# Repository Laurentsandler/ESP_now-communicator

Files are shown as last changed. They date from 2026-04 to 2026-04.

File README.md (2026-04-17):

# ESP-Now long range communicator

## Description

A long range text based communicator based on esp-now

## Motivation

My school banned phones, so I wanted to build a small communicator that me and my friend can use.

## Hardware Design

The custom PCB was designed using EasyEDA, and is 2 layers. The battery fits behind it, the case has locked in buttons.

EasyEDA Project Link:  https://oshwlab.com/capyvara0/esp_now-communicator

### PCB Layout & 3D Renders





### Case





Onshape Project Link: [<ONSHAPE_PROJECT>](https://cad.onshape.com/documents/b60efe79f3e39b50ec4340e8/w/98b2614707c57877de69ff90/e/7286b2544836b97ccc1a2148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)

## Features

- Sending text based data between devices
- Offline detection
- Secure transmition

## System Architecture

```text
Device 1 <----> Device 2
```

## Software Dependencies

Install these libraries:
- #include <Arduino.h>
- #include <WiFi.h>
- #include <esp_now.h>
- #include <Wire.h>
- #include <Adafruit_GFX.h>
- #include <Adafruit_SH110X.h>
  
## Configuration

### Module Setup
1. Connect battery to JST connector
3. Connect the antenna to the esp32 module, and mount it through the hole in the case.
4. Wire the Display: Connect the 1.3" OLED display using I2C (SDA to pin `8`, SCL to pin `9`, VCC to 3.3V, and GND to Ground).
5. Upload Firmware: Open the project in PlatformIO and flash the exact same codebase (`src/main.cpp`) to both ESP32-S3 boards.

## Usage

- Auto-Discovery: Wait up to 3 seconds. The devices will broadcast heartbeat PINGs and automatically lock onto each other's MAC addresses using the PAIRING_SECRET.
- Verify Status: Check the OLED screen; the top status indicator should automatically update from Status: OFFLINE to Status: ONLINE.
- Communicate: Use the 0-9 buttons to type messages (T9 multi-tap style), the bottom-left button (M) to backspace, and the bottom-right button (S) to send the message privately to the paired device

## Bill of Materials (BOM)

| Item | Description | Purpose | Qty | Unit Price | Link | Supplier |
|---|---|---|-----|---|---|---|
| JLCPCB PCB | Custom PCB | Main computer that interfaces with components | 1 | $64.43 | N/A | JLCPCB |
| 1.3" OLED I2C Display (128x64, White) | OLED Display Module | Display messages and content | 2 | $6.36 | [Link](https://fr.aliexpress.com/item/4000191763740.html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) | AliExpress |
| 8dBi WiFi Antenna (2.4GHz) | External WiFi Antenna | Supports long-distance communication | 1 | $5.66 | [Link](https://fr.aliexpress.com/item/1005007449002305.html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) | AliExpress |
| 103450 3.7V 2000mAh LiPo Battery | Lithium Polymer Battery | Main power source | 2 | $7.81 | [Link](https://fr.aliexpress.com/item/1005011659846396.html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) | AliExpress |

## Total Cost
**$84.26**

## License

MIT License

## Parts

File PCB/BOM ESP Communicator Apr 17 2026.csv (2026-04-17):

ID | Name | Designator | Footprint | Quantity | Manufacturer Part | Manufacturer | Supplier | Supplier Part | Price
1 | 10uF | C1,C9 | C0603 | 2 | CL10A106KP8NNNC | SAMSUNG(三星) | LCSC | C19702 | 0.008
2 | 22uF | C2 | C0603 | 1 | CL10A226MQ8NRNC | SAMSUNG(三星) | LCSC | C59461 | 0.009
3 | 100nF | C3 | C0603 | 1 | VJ0603Y104JXQCW1BC | VISHAY(威世) | LCSC | C3834925 | 0.081
4 | 10uF | C4 | C0805 | 1 | CL21A106KAYNNNE | SAMSUNG(三星) | LCSC | C15850 | 0.022
5 | 100nF | C5 | C0805 | 1 | CC0805KRX7R9BB104 | YAGEO(国巨) | LCSC | C49678 | 0.005
6 | 47uF | C6 | C0805 | 1 | C0805X5R476M100NT | SANYEAR(叁叶源) | LCSC | C466799
7 | B5819W_C8598 | D1 | SOD-123_L2.7-W1.6-LS3.7-RD-1 | 1 | B5819W SL | CJ(江苏长电/长晶) | LCSC | C8598 | 0.024
8 | FC-2012HRK-620D | LED1 | LED0805-RD | 1 | NCD0805R1 | 国星光电 | LCSC | C84256 | 0.013
9 | AO3401A | Q1 | SOT-23_L2.9-W1.3-P1.90-LS2.4-BR | 1 | AO3401A | AOS | LCSC | C15127 | 0.059
10 | 5.1kΩ | R1,R2 | R0603 | 2 | 0603WAF5101T5E | UNI-ROYAL(厚声) | LCSC | C23186 | 0.002
11 | 100kΩ | R3 | R0603 | 1 | 0603WAF1003T5E | UNI-ROYAL(厚声) | LCSC | C25803 | 0.002
12 | 2kΩ | R4 | R0603 | 1 | 0603WAF2001T5E | UNI-ROYAL(厚声) | LCSC | C22975 | 0.002
13 | 22Ω | R7,R8 | R0603 | 2 | FRC0603F22R0TS | FOJAN(富捷) | LCSC | C2930077 | 0.001
14 | 10kΩ | R9,R10 | R0603 | 2 | 0603WAF1002T5E | UNI-ROYAL(厚声) | LCSC | C25804 | 0.001
15 | 1kΩ | R5 | R0805 | 1 | FRR0805J102 TS | FOJAN(富捷) | LCSC | C49196827 | 0.002
16 | 100kΩ | R6 | R0805 | 1 | 0805W8F1003T5E | UNI-ROYAL(厚声) | LCSC | C149504 | 0.003
17 | MST-12D18G4 SPDT SLIDE SWITCH | SW1 | SW-SMD_MST-12D18G4-SPDT-SLIDE-SWITCH | 1 | MST-12D18G4 SPDT Slide Switch | SHOU HAN(首韩) | LCSC | C49023767 | 0.082
18 | TS-1088-AR02016 | SW3,SW4 | SW-SMD_L3.9-W3.0-P4.45 | 2 | TS-1088-AR02016 | XUNPU(讯普) | LCSC | C720477 | 0.056
19 | 4*4*1.7 | SW5,SW6,SW7,SW8,SW9,SW10,SW11,SW12,SW13,SW14,SW15,SW16 | SW-SMD_4P-L5.2-W5.2-P3.70-LS6.5 | 12 | 4*4*1.7 贴片 | BOOMELE(博穆精密) | LCSC | C10852 | 0.022
20 | TP4054A | U1 | SOT-23-5_L2.9-W1.6-P0.95-LS2.8-TL | 1 | TP4054A | YONGYUTAI(永裕泰) | LCSC | C33551022 | 0.029
21 | AP2112K-3.3TRG1 | U3 | SOT-25-5_L2.9-W1.6-P0.95-LS2.8-BL | 1 | AP2112K-3.3TRG1 | DIODES(美台) | LCSC | C51118 | 0.147
22 | 1.3Inch I2C OLED MODULE | U4 | OLED 1.3 INCH | 1
23 | ESP32-S3-WROOM-1U-N8 | U17 | WIRELM-SMD_ESP32-S3-WROOM-1U | 1 | ESP32-S3-WROOM-1U-N8 | ESPRESSIF(乐鑫) | LCSC | C2980297 | 4.942
24 | TYPE-C-31-M-12 | USBC1 | USB-C_SMD-TYPE-C-31-M-12_1 | 1 | TYPE-C-31-M-12 | 韩国韩荣 | LCSC | C165948 | 0.185

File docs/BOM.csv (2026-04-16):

Item | Description | Purpose | Qty | Unit Price | Link | Supplier
JLCPCB PCB | Custom PCB | Main computer that interfaces with components | 1 | 64.43 | N/A | JLCPCB
1.3" OLED I2C Display (128x64 White) | OLED Display Module | Display messages and content | 2 | 6.36 | https://fr.aliexpress.com/item/4000191763740.html | AliExpress
8dBi WiFi Antenna (2.4GHz) | External WiFi Antenna | Supports long-distance communication | 1 | 5.66 | https://fr.aliexpress.com/item/1005007449002305.html | AliExpress
103450 3.7V 2000mAh LiPo Battery | Lithium Polymer Battery | Main power source | 2 | 7.81 | https://fr.aliexpress.com/item/1005011659846396.html | AliExpress

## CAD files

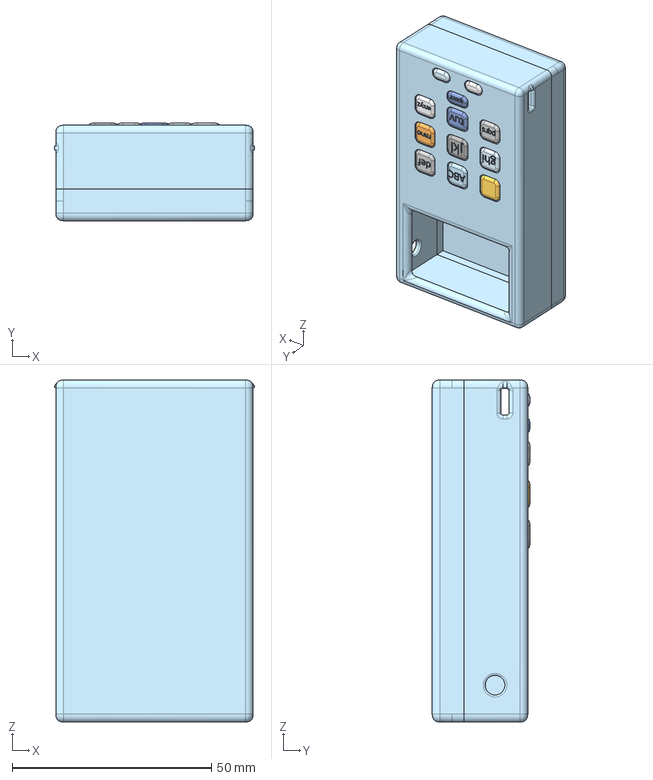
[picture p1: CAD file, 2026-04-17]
CAD/Full Assembly.step
50.3 x 24.5 x 85.9 mm

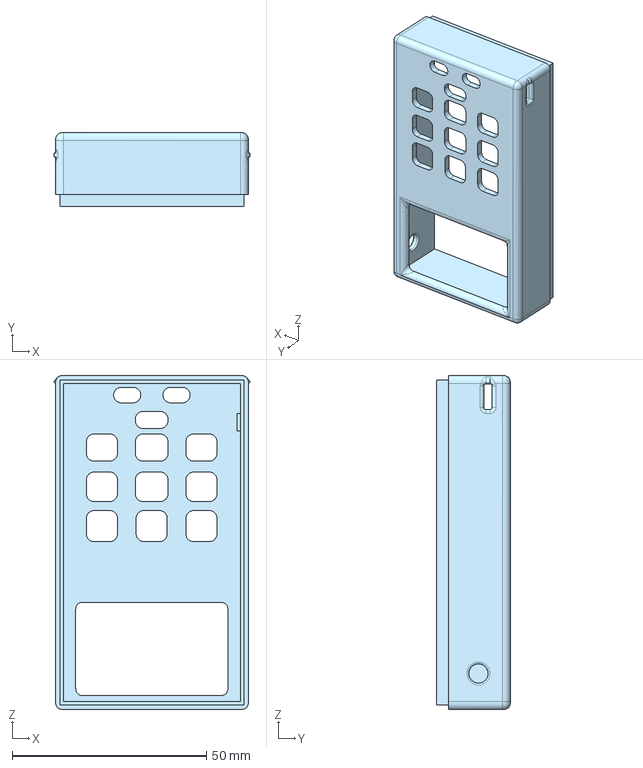
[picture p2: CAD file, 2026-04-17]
CAD/Front Panel.step
50.3 x 19.0 x 85.9 mm

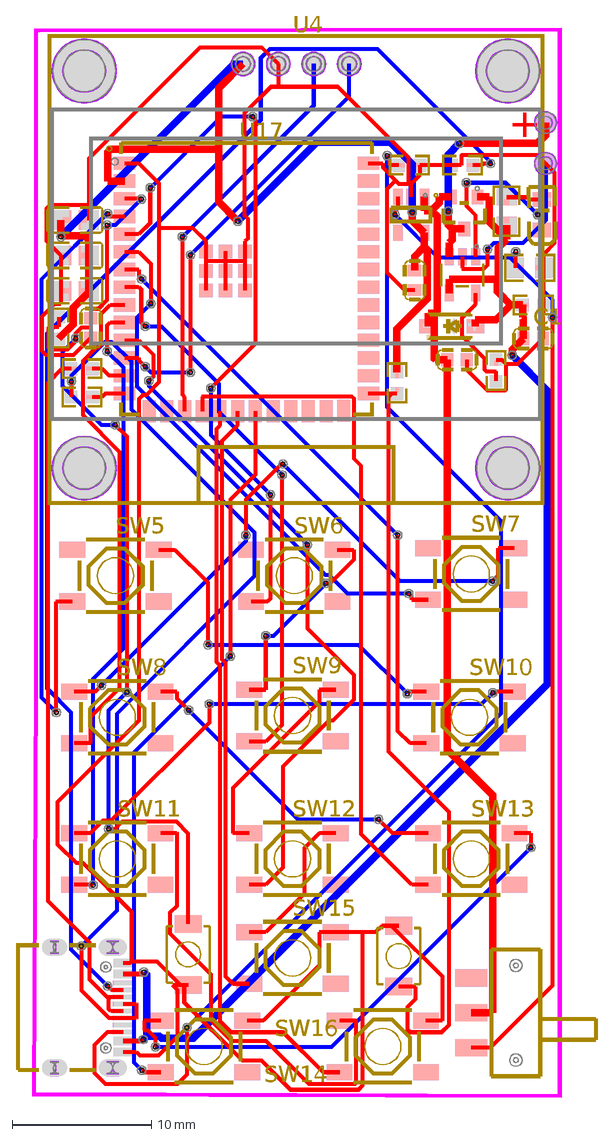
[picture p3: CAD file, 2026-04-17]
PCB/ESP Now Communicator 2026-04-17.dxf
+
C1
SW5
SW6
SW7
SW8
SW9
SW10
SW11
SW12
SW13
SW14
SW15
SW16
U4
U17

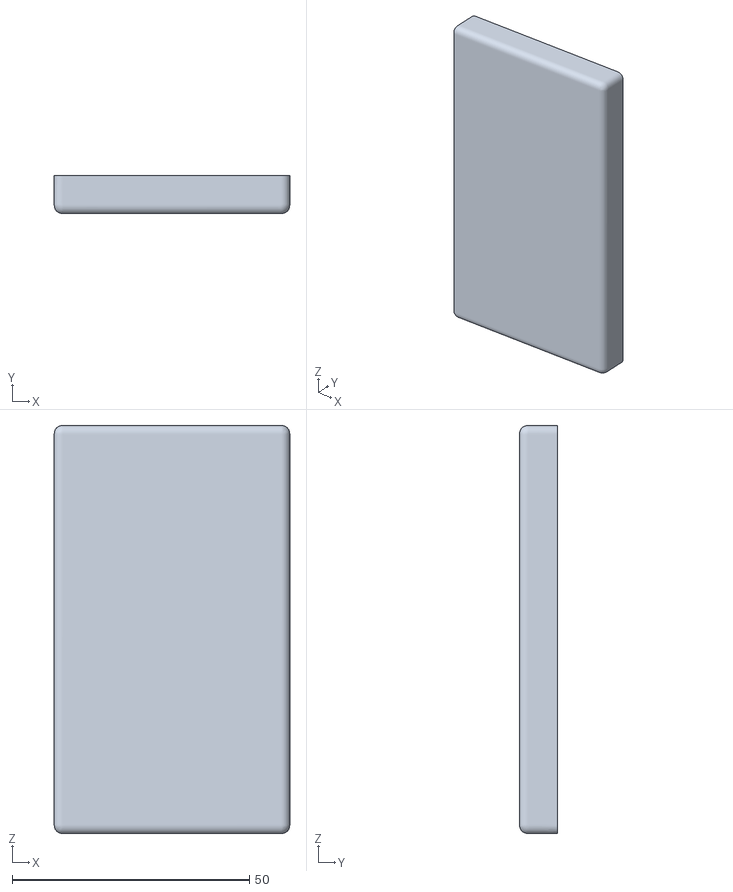
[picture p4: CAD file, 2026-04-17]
CAD/Lid.stl
49.6 x 8.01 x 85.9

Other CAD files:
CAD/Lid (1).step
CAD/Front Panel.stl
CAD/Full Assembly.stl

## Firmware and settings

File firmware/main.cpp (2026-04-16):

#include <Arduino.h>
#include <WiFi.h>
#include <esp_now.h>
#include <Wire.h>
#include <Adafruit_GFX.h>
#include <Adafruit_SH110X.h> // Most 1.3" OLEDs use the SH1106 controller

#define SCREEN_WIDTH 128
#define SCREEN_HEIGHT 64
#define OLED_RESET -1
#define SCREEN_ADDRESS 0x3C    // Typical I2C address for 1.3" OLEDs

Adafruit_SH1106G display = Adafruit_SH1106G(SCREEN_WIDTH, SCREEN_HEIGHT, &Wire, OLED_RESET);

// --- Button Setup ---
const int numButtons = 12;
const byte buttonPins[numButtons] = {4, 5, 6, 7, 15, 16, 17, 18, 10, 11, 12, 13};
const char buttonChars[numButtons] = {'1', '2', '3', '4', '5', '6', '7', '8', '9', 'M', '0', 'S'};

#define NO_KEY '\0'

char getCustomKey() {
  static unsigned long lastDebounceTime = 0;
  static char lastStableChar = NO_KEY;
  static char lastReading = NO_KEY;
  const unsigned long debounceDelay = 50;

  char currentReading = NO_KEY;
  for (int i = 0; i < numButtons; i++) {
    if (digitalRead(buttonPins[i]) == LOW) {
      currentReading = buttonChars[i];
      break;
    }
  }

  if (currentReading != lastReading) {
    lastDebounceTime = millis();
  }

  char finalKey = NO_KEY;
  if ((millis() - lastDebounceTime) > debounceDelay) {
    if (currentReading != lastStableChar) {
      lastStableChar = currentReading;
      if (lastStableChar != NO_KEY) {
        finalKey = lastStableChar;
      }
    }
  }
  
  lastReading = currentReading;
  return finalKey;
}

// --- Multi-tap (T9 style) Setup ---
const char* const t9map[10] = {
  " 0",      // 0 button: Space, 0
  ".,?!1",   // 1 button: Punctuation, 1
  "abc2",    // 2 button
  "def3",    // 3 button
  "ghi4",    // 4 button
  "jkl5",    // 5 button
  "mno6",    // 6 button
  "pqrs7",   // 7 button
  "tuv8",    // 8 button
  "wxyz9"    // 9 button
};

char currentMsg[64] = "";
int msgLen = 0;
char receivedMsg[64] = "";
bool newMsgReceived = false;

char lastKey = NO_KEY;
unsigned long lastPressTime = 0;
int t9Index = 0;

// Broadcast MAC Address (FF:FF:FF:FF:FF:FF) 
// This sends to any listener so no need to hardcode each device's specific MAC.
uint8_t broadcastAddress[] = {0xFF, 0xFF, 0xFF, 0xFF, 0xFF, 0xFF};

#define MSG_TYPE_PING 0
#define MSG_TYPE_TEXT 1

const uint32_t PAIRING_SECRET = 0x1A2B3C4D; // Unique app ID so they only pair with each other

typedef struct struct_message {
  uint8_t msgType;
  uint32_t secret;
  char txt[64];
} struct_message;

uint8_t peerAddress[6] = {0, 0, 0, 0, 0, 0};
bool peerDiscovered = false;
unsigned long lastSeenTime = 0;
unsigned long lastPingTime = 0;

esp_now_peer_info_t peerInfo;

bool isOnline() {
  return peerDiscovered && ((millis() - lastSeenTime) <= 10000);
}

void OnDataSent(const uint8_t *mac_addr, esp_now_send_status_t status) {
  Serial.print("Last Packet Send Status: ");
  Serial.println(status == ESP_NOW_SEND_SUCCESS ? "Delivery Success" : "Delivery Fail");
}

void OnDataRecv(const uint8_t * mac, const uint8_t *incomingData, int len) {
  if (len != sizeof(struct_message)) return;
  
  struct_message incomingMsg;
  memcpy(&incomingMsg, incomingData, sizeof(incomingMsg));
  
  if (incomingMsg.secret == PAIRING_SECRET) {
    if (incomingMsg.msgType == MSG_TYPE_PING) {
      if (!peerDiscovered || memcmp(peerAddress, mac, 6) != 0) {
        memcpy(peerAddress, mac, 6);
        peerDiscovered = true;
        
        if (!esp_now_is_peer_exist(peerAddress)) {
          esp_now_peer_info_t specificPeer;
          memset(&specificPeer, 0, sizeof(specificPeer));
          memcpy(specificPeer.peer_addr, peerAddress, 6);
          specificPeer.channel = 0;
          specificPeer.encrypt = false;
          esp_now_add_peer(&specificPeer);
        }
      }
      lastSeenTime = millis();
    } else if (incomingMsg.msgType == MSG_TYPE_TEXT) {
      lastSeenTime = millis();
      strncpy(receivedMsg, incomingMsg.txt, sizeof(receivedMsg));
      receivedMsg[sizeof(receivedMsg)-1] = '\0';
      newMsgReceived = true;
    }
  }
}

void updateDisplay() {
  display.clearDisplay();
  
  display.setTextSize(1);
  display.setTextColor(SH110X_WHITE);
  
  // Status Indicator
  display.setCursor(0, 0);
  if (isOnline()) {
    display.println("Status: ONLINE");
  } else {
    display.println("Status: OFFLINE");
  }
  
  // Received Message Section
  display.setCursor(0, 10);
  display.println("Received:");
  display.setCursor(0, 20);
  display.println(receivedMsg);
  
  // Divider line
  display.drawLine(0, 31, 128, 31, SH110X_WHITE);
  
  // Typing Message Section
  display.setCursor(0, 36);
  display.println("You:");
  display.setCursor(0, 46);
  display.print(currentMsg);

  display.display();
}

void setup() {
  Serial.begin(115200);

  // Initialize buttons
  for (int i = 0; i < numButtons; i++) {
    pinMode(buttonPins[i], INPUT_PULLUP);
  }

  // Initialize display
  Wire.begin(8, 9);
  // Use typical I2C pins for your ESP32-S3 (SDA/SCL usually 8/9, but check your board map)
  if(!display.begin(SCREEN_ADDRESS, true)) {
    Serial.println(F("SH1106 allocation failed"));
    for(;;); // Don't proceed, loop forever
  }
  display.clearDisplay();
  display.display();

  // Initialize ESP-NOW
  WiFi.mode(WIFI_STA); // Set device as a Wi-Fi Station
  if (esp_now_init() != ESP_OK) {
    Serial.println("Error initializing ESP-NOW");
    return;
  }
  
  esp_now_register_send_cb(OnDataSent);
  esp_now_register_recv_cb(OnDataRecv);

  // Register broadcast peer
  memset(&peerInfo, 0, sizeof(peerInfo));
  memcpy(peerInfo.peer_addr, broadcastAddress, 6);
  peerInfo.channel = 0;  
  peerInfo.encrypt = false;
  
  if (esp_now_add_peer(&peerInfo) != ESP_OK) {
    Serial.println("Failed to add peer");
    return;
  }

  updateDisplay();
}

void loop() {
  char key = getCustomKey();
  
  if (key != NO_KEY) {
    unsigned long now = millis();
    
    // T9 Text Entry Logic for buttons 0-9
    if (key >= '0' && key <= '9') {
      int num = key - '0';
      int mapLen = strlen(t9map[num]);

      if (key == lastKey && (now - lastPressTime) < 1000) {
        // Cycle to next letter if pressed same key within 1 second
        t9Index = (t9Index + 1) % mapLen;
        if (msgLen > 0) {
          currentMsg[msgLen - 1] = t9map[num][t9Index]; // Swap last character
        }
      } else {
        // Start entering a new character
        t9Index = 0;
        if (msgLen < 63) { // Ensure buffer doesn't overflow
          currentMsg[msgLen] = t9map[num][t9Index];
          currentMsg[msgLen + 1] = '\0';
          msgLen++;
        }
      }
      lastKey = key;
      lastPressTime = now;
      updateDisplay();
    }
    else if (key == 'S') { 
      // 'S' mapped to: SEND MESSAGE
      if (peerDiscovered) {
        struct_message outgoingMsg;
        outgoingMsg.msgType = MSG_TYPE_TEXT;
        outgoingMsg.secret = PAIRING_SECRET;
        strncpy(outgoingMsg.txt, currentMsg, sizeof(outgoingMsg.txt));
        outgoingMsg.txt[sizeof(outgoingMsg.txt)-1] = '\0';
        
        esp_now_send(peerAddress, (uint8_t *) &outgoingMsg, sizeof(outgoingMsg));
      }
      
      // Clear input buffer after send
      memset(currentMsg, 0, sizeof(currentMsg));
      msgLen = 0;
      lastKey = NO_KEY;
      updateDisplay();
    }
    else if (key == 'M') { 
      // 'M' mapped to: MENU or BACKSPACE/DELETE
      if (msgLen > 0) {
        msgLen--;
        currentMsg[msgLen] = '\0';
      }
      lastKey = NO_KEY;
      updateDisplay();
    }
  }

  // Auto lock in the typed character after 1 second of inactivity
  if (lastKey != NO_KEY && (millis() - lastPressTime) > 1000) {
    lastKey = NO_KEY;
  }
  
  // Check if we got something new via ESP-NOW to update the screen
  if (newMsgReceived) {
    newMsgReceived = false;
    updateDisplay();
  }
  
  // Send PING every 3 seconds
  unsigned long currentMillisMillis = millis();
  if (currentMillisMillis - lastPingTime >= 3000) {
    lastPingTime = currentMillisMillis;
    struct_message pingMsg;
    pingMsg.msgType = MSG_TYPE_PING;
    pingMsg.secret = PAIRING_SECRET;
    pingMsg.txt[0] = '\0';
    esp_now_send(broadcastAddress, (uint8_t *) &pingMsg, sizeof(pingMsg));
  }
  
  // Update display if online status changes
  static bool lastOnlineStatus = false;
  bool currentStatus = isOnline();
  if (currentStatus != lastOnlineStatus) {
    lastOnlineStatus = currentStatus;
    updateDisplay();
  }
}
